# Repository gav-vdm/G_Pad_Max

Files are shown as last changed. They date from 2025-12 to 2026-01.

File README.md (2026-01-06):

# G_Pad_Max

# BOM:
- 8x Cherry MX switches
- 1x EC11 Encoder
- 1x PCB
- 9x Through-hole 1N4148 Diodes
- 16x SK6812 MINI-E LEDs
- 1x 0.91 inch OLED displays
- 8x Blank DSA keycaps
- 1x Seeed XIAO RP2040
- 1x 3D PRINTED CASE
# Images 
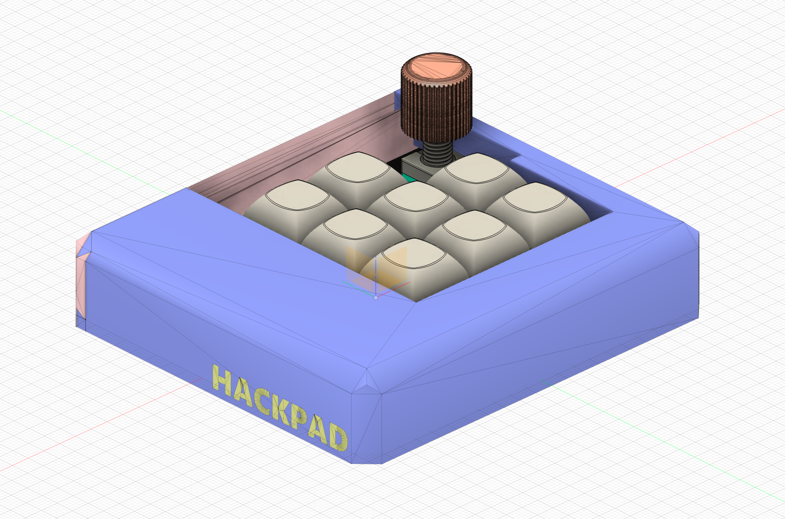
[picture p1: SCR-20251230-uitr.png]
- 
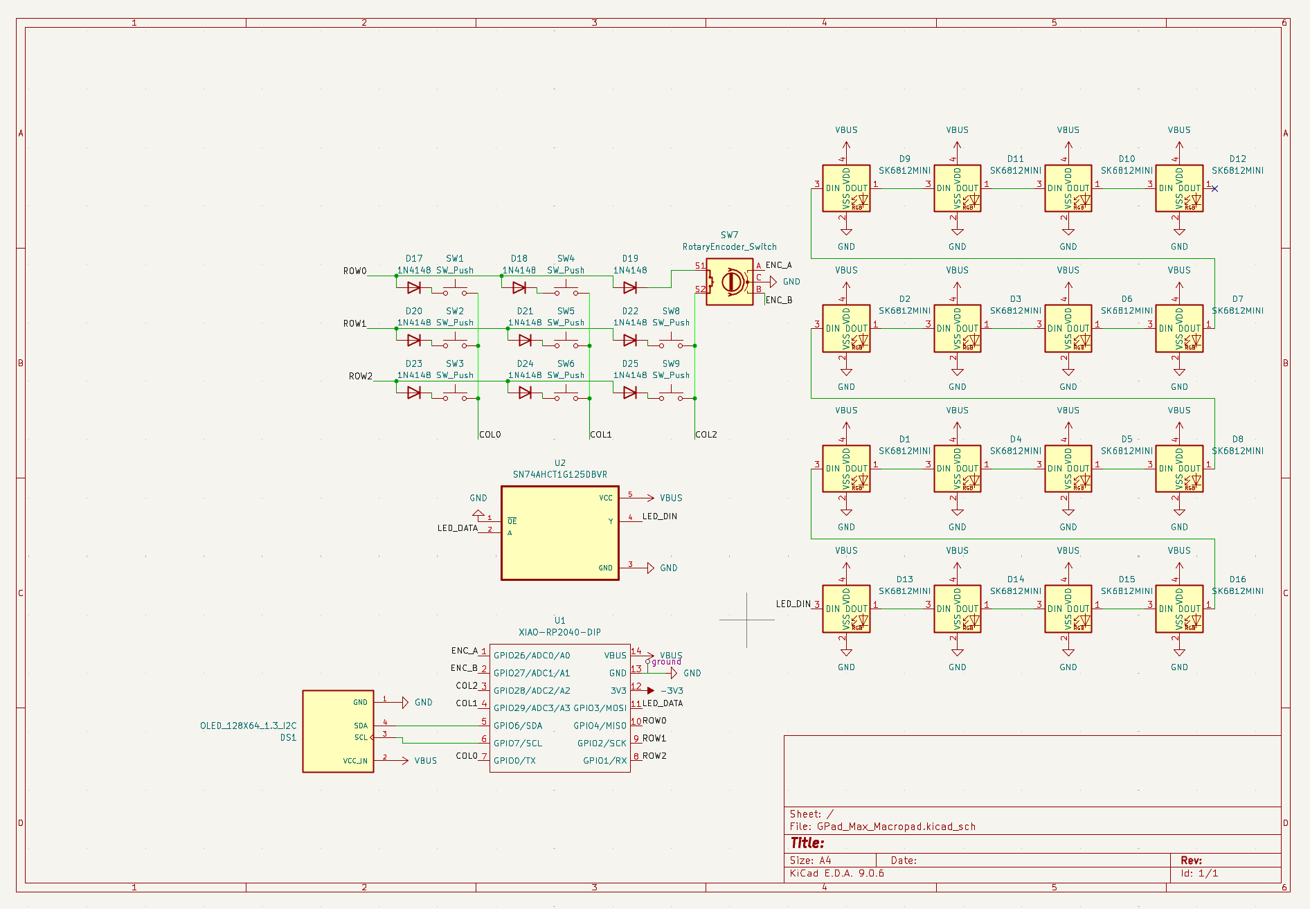
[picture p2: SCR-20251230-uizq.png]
- 
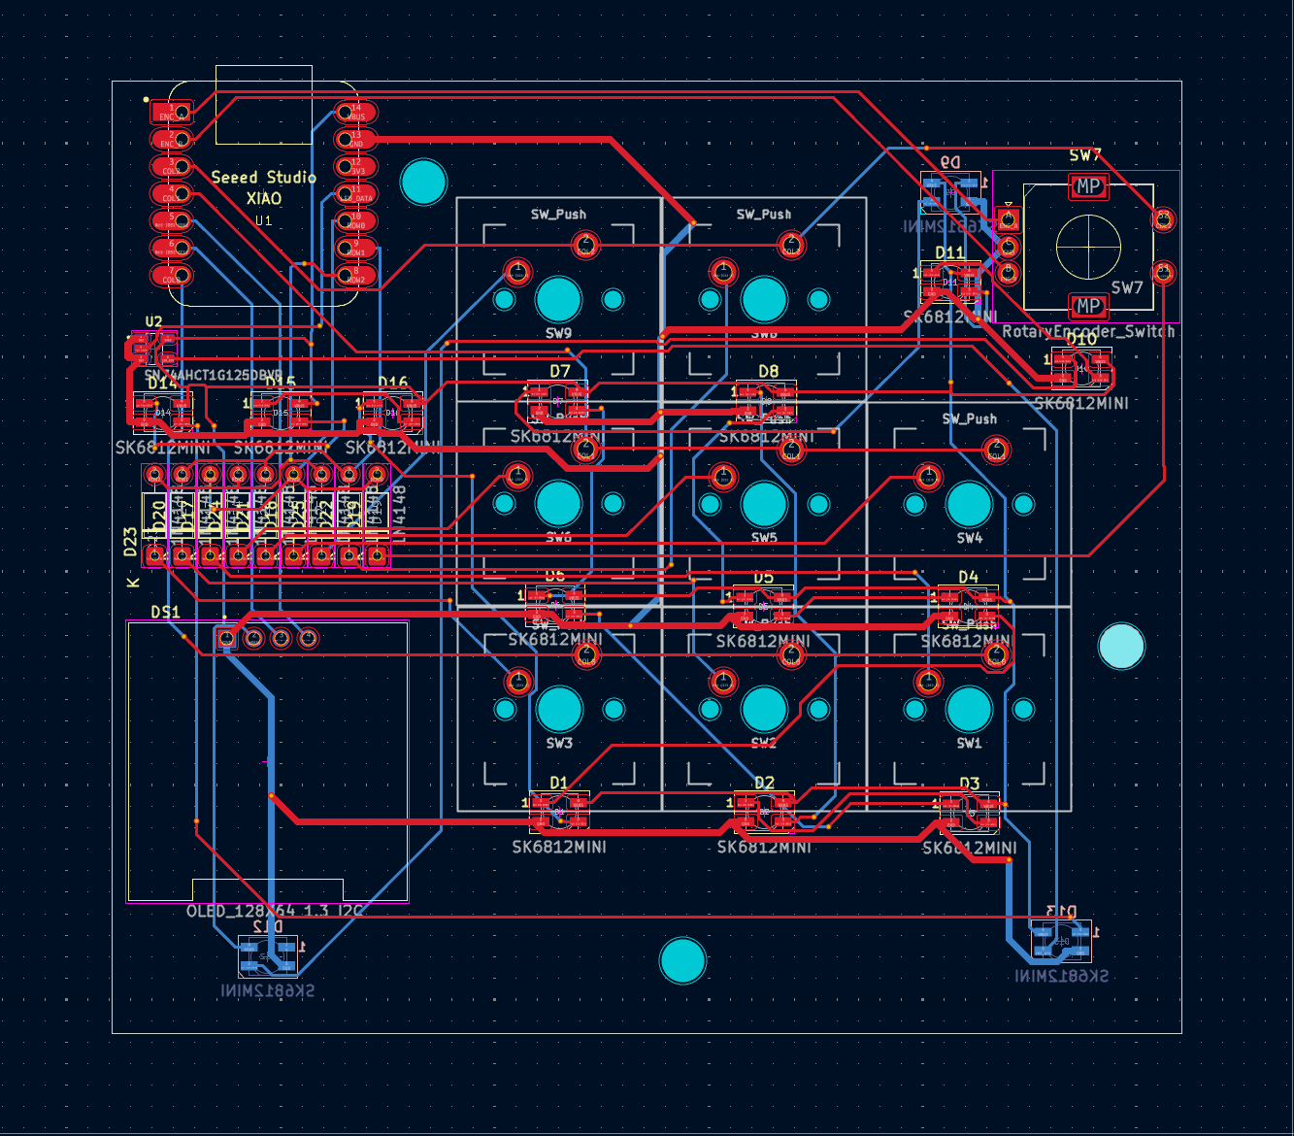
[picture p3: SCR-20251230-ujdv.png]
- 
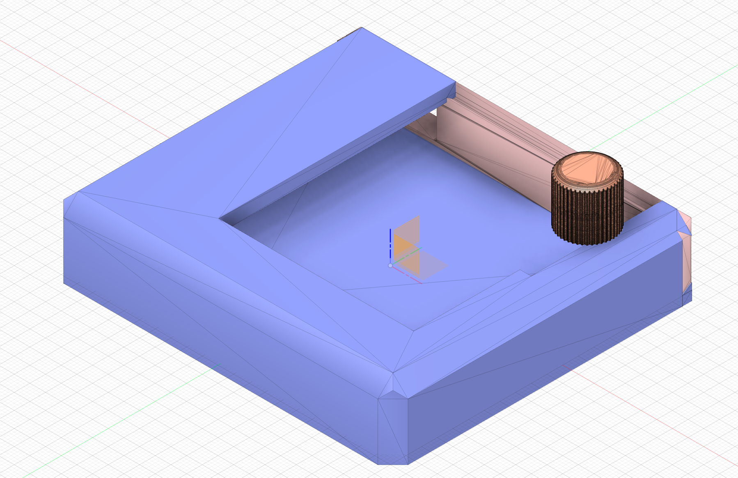
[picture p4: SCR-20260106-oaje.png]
- 

# Info
I want to make a few iterations on the case when I physically have the PCB so for now it is just temporary to get the sizing right. 

I also need to review the firmware when I assemble the pcb. 

# Extra
- There is a option to add a level switcher to make the signalling better for the LEDs but for now I'm just going to bridge the pads and skip it.

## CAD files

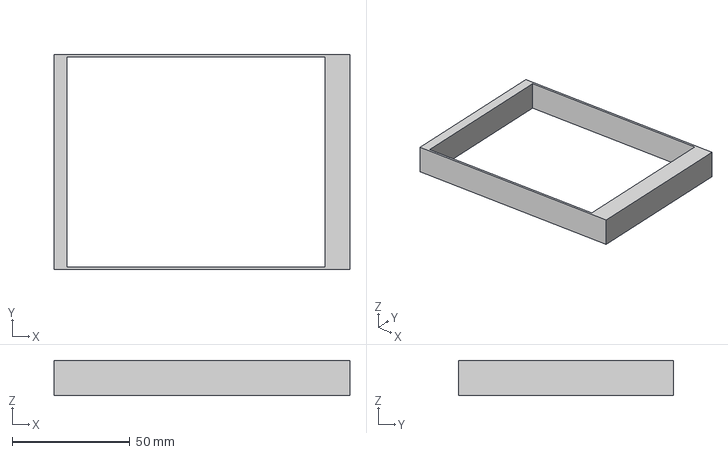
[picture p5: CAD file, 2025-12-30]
cad/G_Pad_Max.step
125.7 x 91.4 x 15.0 mm

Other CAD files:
cad/HackPad Body V1.step

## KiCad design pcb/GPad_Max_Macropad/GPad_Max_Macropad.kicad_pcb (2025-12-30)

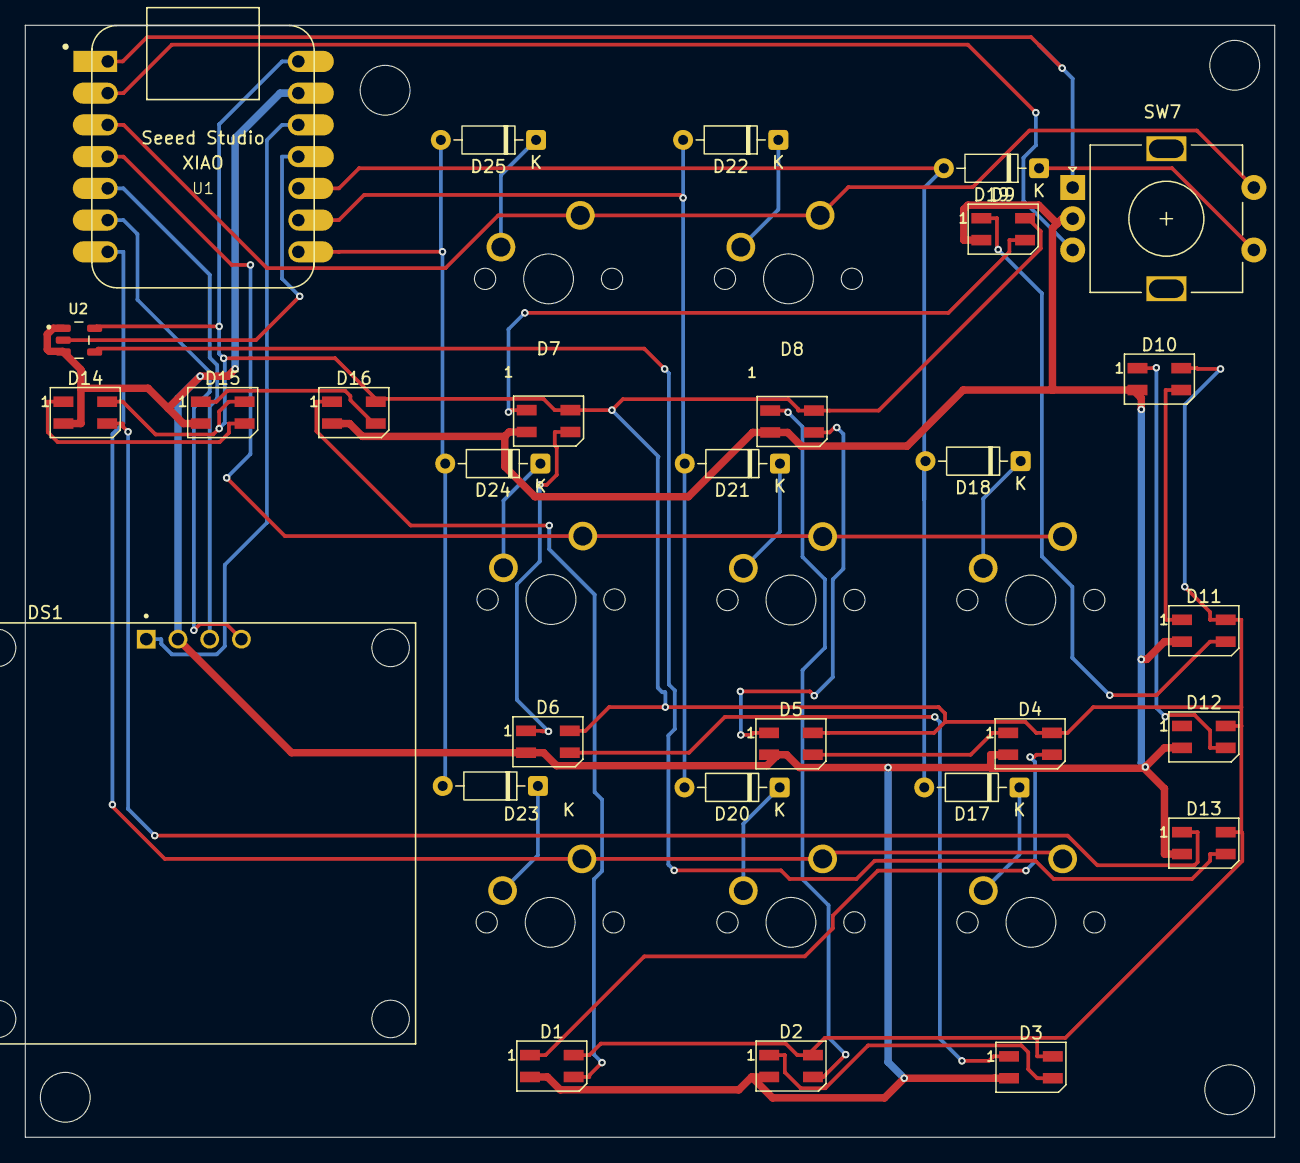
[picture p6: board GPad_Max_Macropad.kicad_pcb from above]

Board: 2 copper layers, 100.0 x 89.0 mm, 37 parts (0 on the bottom side), 39 nets.

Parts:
D1, D2, D3, D4, D5, D6, D7, D8, D9, D10, D11, D12, D13, D14, D15, D16: SK6812MINI; LED_SK6812MINI_PLCC4_3.5x3.5mm_P1.75mm
D17, D18, D19, D20, D21, D22, D23, D24, D25: 1N4148; D_DO-35_SOD27_P7.62mm_Horizontal
DS1: OLED_128X64_1.3_I2C; LCD_OLED_128X64_1.3_I2C
SW1, SW2, SW3, SW4, SW5, SW6, SW8, SW9: SW_Push; MX-Solderable-1U
SW7: RotaryEncoder_Switch; RotaryEncoder_Alps_EC11E-Switch_Vertical_H20mm
U1: XIAO-RP2040-DIP; XIAO-Generic-Hybrid-14P-2.54-21X17.8MM
U2: SN74AHCT1G125DBVR; SOT95P280X145-5N

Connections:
-3V3: DS1.1 (VDD), U1.12 (3V3)
/COL0: SW1.2, SW2.2, SW3.2, U1.7 (GPIO0/TX)
/COL1: SW4.2, SW5.2, SW6.2, U1.4 (GPIO29/ADC3/A3)
/COL2: SW7.S2, SW8.2, SW9.2, U1.3 (GPIO28/ADC2/A2)
/ENC_A: SW7.A, U1.1 (GPIO26/ADC0/A0)
/ENC_B: SW7.B, U1.2 (GPIO27/ADC1/A1)
/LED_DATA: U1.11 (GPIO3/MOSI), U2.2 (A)
/LED_DIN: D13.3 (DIN), U2.4 (Y)
/ROW0: D17.2 (A), D18.2 (A), D19.2 (A), U1.10 (GPIO4/MISO)
/ROW1: D20.2 (A), D21.2 (A), D22.2 (A), U1.9 (GPIO2/SCK)
/ROW2: D23.2 (A), D24.2 (A), D25.2 (A), U1.8 (GPIO1/RX)
GND: D1.2 (VSS), D2.2 (VSS), D3.2 (VSS), D4.2 (VSS), D5.2 (VSS), D6.2 (VSS), D7.2 (VSS), D8.2 (VSS), D9.2 (VSS), D10.2 (VSS), D11.2 (VSS), D12.2 (VSS), D13.2 (VSS), D14.2 (VSS), D15.2 (VSS), D16.2 (VSS), DS1.2 (GND), SW7.C, U1.13 (GND), U2.1 (~OE), U2.3 (GND)
unnamed: D1.3 (DIN), D16.1 (DOUT)
unnamed: D1.1 (DOUT), D4.3 (DIN)
unnamed: D2.3 (DIN), D8.1 (DOUT)
unnamed: D2.1 (DOUT), D3.3 (DIN)
unnamed: D3.1 (DOUT), D6.3 (DIN)
unnamed: D4.1 (DOUT), D5.3 (DIN)
unnamed: D5.1 (DOUT), D8.3 (DIN)
unnamed: D6.1 (DOUT), D7.3 (DIN)
unnamed: D7.1 (DOUT), D9.3 (DIN)
unnamed: D10.3 (DIN), D11.1 (DOUT)
unnamed: D10.1 (DOUT), D12.3 (DIN)
unnamed: D9.1 (DOUT), D11.3 (DIN)
unnamed: D13.1 (DOUT), D14.3 (DIN)
unnamed: D14.1 (DOUT), D15.3 (DIN)
unnamed: D15.1 (DOUT), D16.3 (DIN)
unnamed: D17.1 (K), SW1.1
unnamed: D18.1 (K), SW4.1
unnamed: D19.1 (K), SW7.S1
unnamed: D20.1 (K), SW2.1
unnamed: D21.1 (K), SW5.1
unnamed: D22.1 (K), SW8.1
unnamed: D23.1 (K), SW3.1
unnamed: D24.1 (K), SW6.1
unnamed: D25.1 (K), SW9.1
unnamed: DS1.3 (SCK), U1.5 (GPIO6/SDA)
unnamed: DS1.4 (SDA), U1.6 (GPIO7/SCL)
VBUS: D1.4 (VDD), D2.4 (VDD), D3.4 (VDD), D4.4 (VDD), D5.4 (VDD), D6.4 (VDD), D7.4 (VDD), D8.4 (VDD), D9.4 (VDD), D10.4 (VDD), D11.4 (VDD), D12.4 (VDD), D13.4 (VDD), D14.4 (VDD), D15.4 (VDD), D16.4 (VDD), U1.14 (VBUS), U2.5 (VCC)
